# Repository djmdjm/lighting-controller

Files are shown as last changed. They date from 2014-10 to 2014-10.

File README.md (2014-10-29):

Photographic Lighting Timer
===========================

This is a small lighting controller circuit based around an AVR
microcontroller. It supports two inputs and two outputs and
configurable timing delays. The outputs use MOSFETs that should
be good for up to 50VDC and 20A.

The `board/` directory contains the Eagle files for the board and
`firmware/` contains the source for the firmware. You'll need
avr-gcc et al. to build it. `make load` will attempt to program
the firmware using my setup (avrdude w/ buspirate on
`/dev/cuaU1`).

NB. the current version of the board has not been built and the
old version that I did build had some problems that required a
bit of rework. I beat the old version into working shape and that
was good enough for my immediate needs.

Not included in the schematics are the front-panel controls: a
power toggle, momentary switch, generic rotary encoder (w/ press
switch) and 4x20 HD44870-style LCD. The switches and encoder need
pull-ups and debouncing caps.

The firmware allows triggering from logical combinations of the
inputs (e.g. "input 1 high and input 2 low"). Upon triggering it
waits a configurable delay (from 1us to ~1ksec) and enables one
or both outputs for a configurable duration. It also supports a
strobe mode that goes from milli-hertz to close to 1MHz frequency
and has adjustable duration and duty cycle.

The outputs are not isolated from each other, but they are
isolated from the inputs and the main board. Likewise the inputs
are isolated from the main board and the output but not from each
other.

This was only my 2nd attempt at cutting a board, so it's probably
terrible. You have been warned :)

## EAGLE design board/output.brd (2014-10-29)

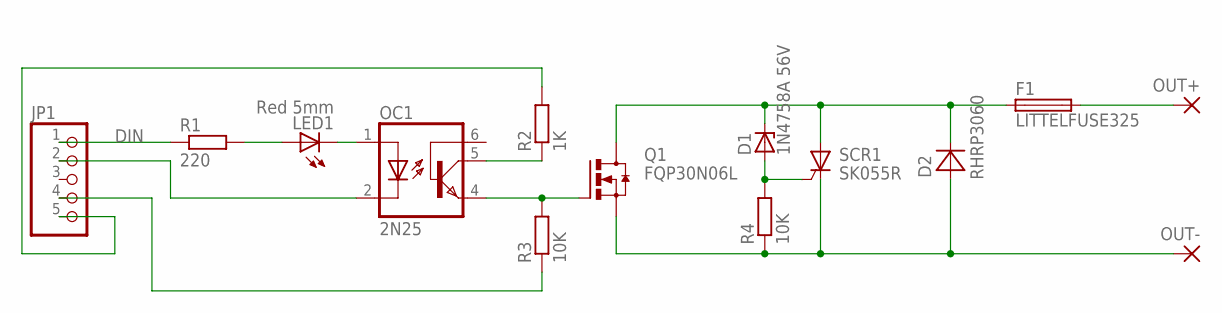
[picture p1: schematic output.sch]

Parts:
D1: 1N4758A 56V; DO41Z10
D2: RHRP3060; TO-220CAS-HS
F1: LITTELFUSE325; LITTELFUSE-325
JP1: PINHD-1X5; 1X05
LED1: Red 5mm; LED5MM
OC1: 2N25; DIL-06
OUT+: 2,54/1,1
OUT-: 2,54/1,1
Q1: FQP30N06L; TO-220BV-HS
R1: 220; 0207/10
R2: 1K; 0207/10
R3, R4: 10K; 0207/10
SCR1: SK055R; TO-220V-HS

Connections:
DGND: JP1.2, OC1.2 (C)
DIN: JP1.1, R1.1
ISOL_GND: JP1.4, R3.1
ISOL_OUT+: D1.C, D2.C, F1.P$1 (1), Q1.D, SCR1.2 (A)
ISOL_OUT-: D2.A, OUT-.1, Q1.S, R4.1, SCR1.1 (C)
ISOL_VDD: JP1.5, R2.2
unnamed: D1.A, R4.2, SCR1.3 (G)
unnamed: OC1.5 (COL), R2.1
unnamed: OC1.4 (EMI), Q1.G, R3.2
unnamed: LED1.K (C), OC1.1 (A)
unnamed: LED1.A, R1.2
unnamed: F1.P$2 (2), OUT+.1

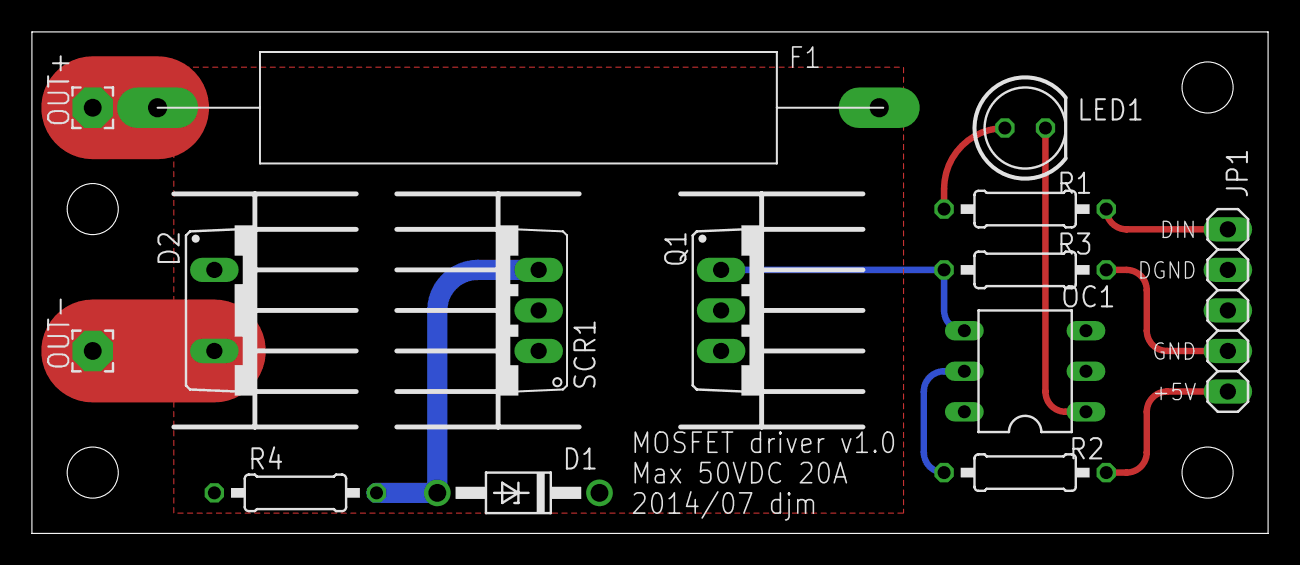
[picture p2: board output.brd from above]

Board: 2 copper layers, 77.5 x 31.4 mm, 14 parts (0 on the bottom side), 12 nets.

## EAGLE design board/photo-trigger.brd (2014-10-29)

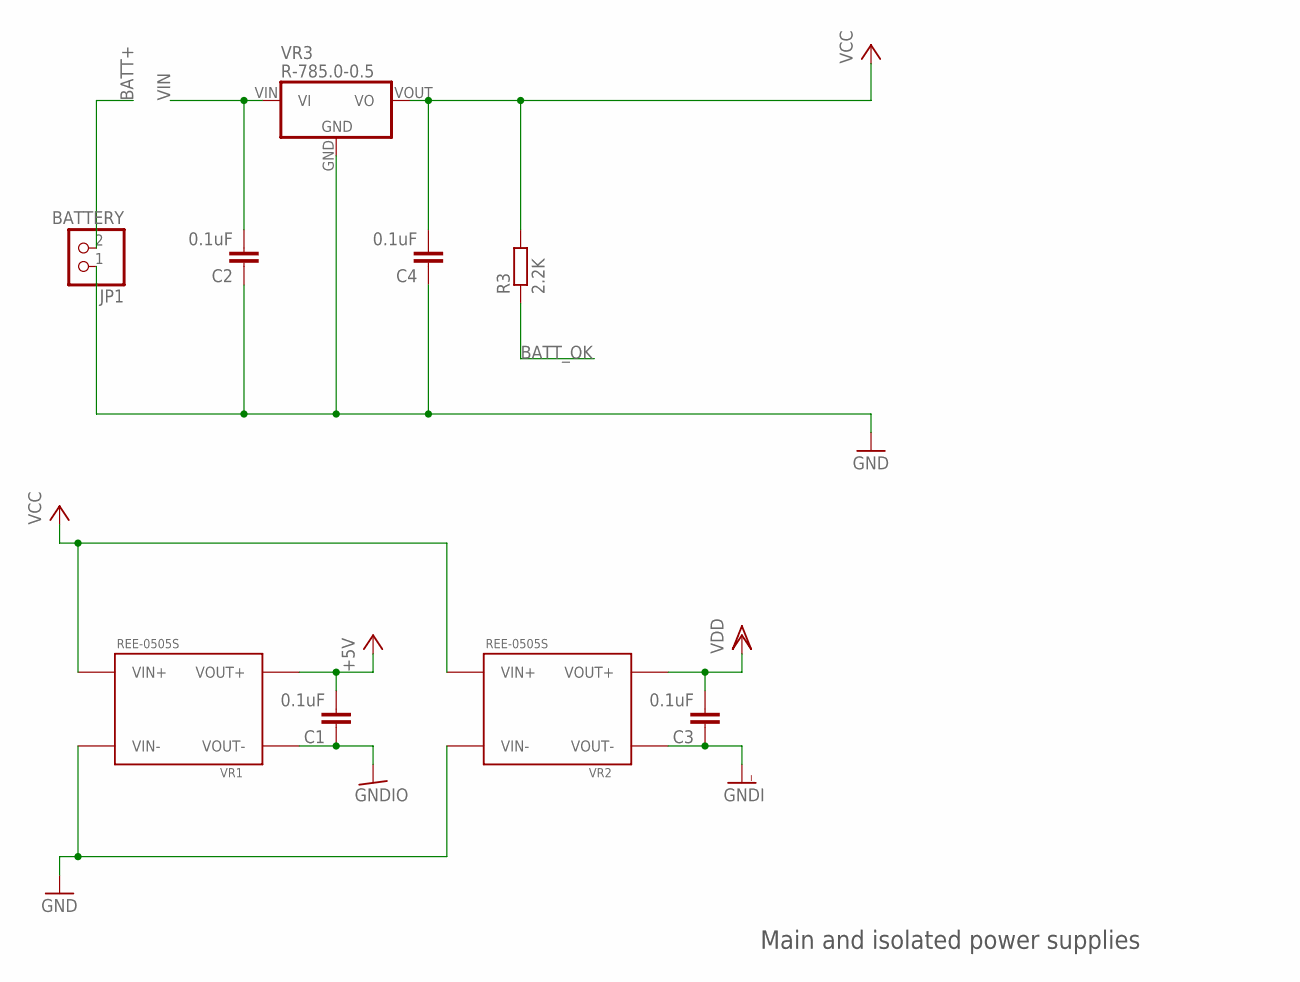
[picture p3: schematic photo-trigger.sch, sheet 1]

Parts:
C1, C2, C3, C4: 0.1uF; C050-035X075
JP1: BATTERY; 1X02
R3: 2.2K; 0207/10
VR1, VR2: REE-0505S; RECOM-REE
VR3: R-785.0-0.5; RECOM-R78

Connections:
+5V: C1.2, VR1.VOUT+; also elsewhere on the board
BATT+: JP1.2; also elsewhere on the board
BATT_OK: R3.1; also elsewhere on the board
GND: C2.1, C4.1, JP1.1, VR1.VIN-, VR2.VIN-, VR3.GND; also elsewhere on the board
GNDI: C3.1, VR2.VOUT-; also elsewhere on the board
GNDIO: C1.1, VR1.VOUT-; also elsewhere on the board
VCC: C4.2, R3.2, VR1.VIN+, VR2.VIN+, VR3.VOUT (VO); also elsewhere on the board
VDD: C3.2, VR2.VOUT+; also elsewhere on the board
VIN: C2.2, VR3.VIN (VI); also elsewhere on the board

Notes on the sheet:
Main and isolated power supplies

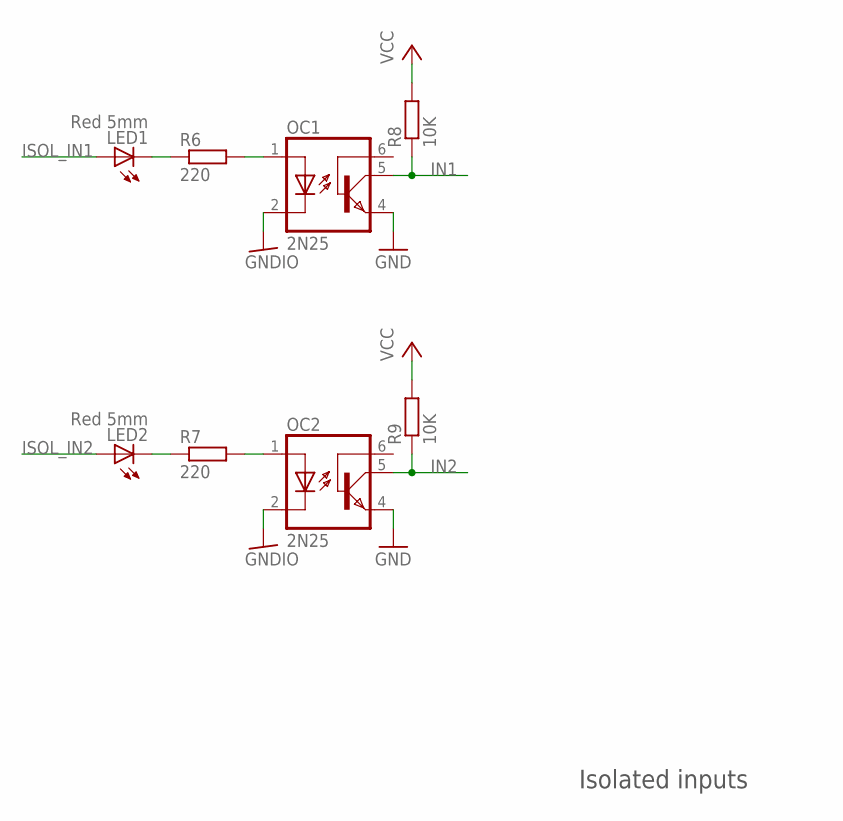
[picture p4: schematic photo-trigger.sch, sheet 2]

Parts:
LED1, LED2: Red 5mm; LED5MM
OC1, OC2: 2N25; DIL-06
R6, R7: 220; 0207/10
R8, R9: 10K; 0207/10

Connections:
GND: OC1.4 (EMI), OC2.4 (EMI); also elsewhere on the board
GNDIO: OC1.2 (C), OC2.2 (C); also elsewhere on the board
IN1: OC1.5 (COL), R8.1; also elsewhere on the board
IN2: OC2.5 (COL), R9.1; also elsewhere on the board
ISOL_IN1: LED1.A; also elsewhere on the board
ISOL_IN2: LED2.A; also elsewhere on the board
unnamed: OC1.1 (A), R6.2
unnamed: OC2.1 (A), R7.2
unnamed: LED2.K (C), R7.1
unnamed: LED1.K (C), R6.1
VCC: R8.2, R9.2; also elsewhere on the board

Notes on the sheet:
Isolated inputs

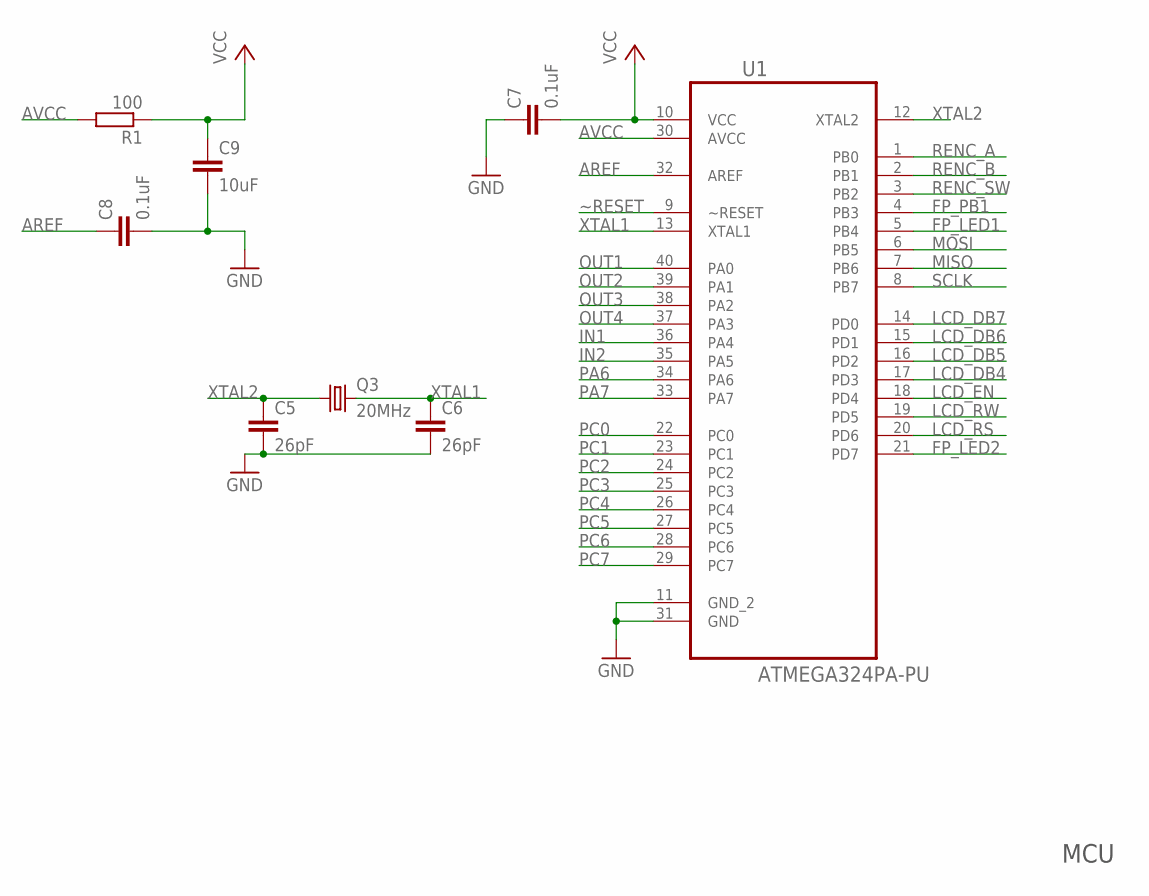
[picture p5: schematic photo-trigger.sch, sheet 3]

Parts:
C5, C6: 26pF; C025-025X050
C7, C8: 0.1uF; C050-035X075
C9: 10uF; C050-035X075
Q3: 20MHz; HC49/S
R1: 100; 0207/10
U1: ATMEGA324PA-PU; DIP254P1524X482-40

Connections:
AREF: C8.1, U1.32 (AREF)
AVCC: R1.2, U1.30 (AVCC)
FP_LED1: U1.5 (PB4); also elsewhere on the board
FP_LED2: U1.21 (PD7); also elsewhere on the board
FP_PB1: U1.4 (PB3); also elsewhere on the board
GND: C5.2, C6.2, C7.1, C8.2, C9.2, U1.11 (GND_2), U1.31 (GND); also elsewhere on the board
IN1: U1.36 (PA4); also elsewhere on the board
IN2: U1.35 (PA5); also elsewhere on the board
LCD_DB4: U1.17 (PD3); also elsewhere on the board
LCD_DB5: U1.16 (PD2); also elsewhere on the board
LCD_DB6: U1.15 (PD1); also elsewhere on the board
LCD_DB7: U1.14 (PD0); also elsewhere on the board
LCD_EN: U1.18 (PD4); also elsewhere on the board
LCD_RS: U1.20 (PD6); also elsewhere on the board
LCD_RW: U1.19 (PD5); also elsewhere on the board
MISO: U1.7 (PB6); also elsewhere on the board
MOSI: U1.6 (PB5); also elsewhere on the board
OUT1: U1.40 (PA0); also elsewhere on the board
OUT2: U1.39 (PA1); also elsewhere on the board
OUT3: U1.38 (PA2); also elsewhere on the board
OUT4: U1.37 (PA3); also elsewhere on the board
PA6: U1.34 (PA6); also elsewhere on the board
PA7: U1.33 (PA7); also elsewhere on the board
PC0: U1.22 (PC0); also elsewhere on the board
PC1: U1.23 (PC1); also elsewhere on the board
PC2: U1.24 (PC2); also elsewhere on the board
PC3: U1.25 (PC3); also elsewhere on the board
PC4: U1.26 (PC4); also elsewhere on the board
PC5: U1.27 (PC5); also elsewhere on the board
PC6: U1.28 (PC6); also elsewhere on the board
PC7: U1.29 (PC7); also elsewhere on the board
RENC_A: U1.1 (PB0); also elsewhere on the board
RENC_B: U1.2 (PB1); also elsewhere on the board
RENC_SW: U1.3 (PB2); also elsewhere on the board
SCLK: U1.8 (PB7); also elsewhere on the board
VCC: C7.2, C9.1, R1.1, U1.10 (VCC); also elsewhere on the board
XTAL1: C6.1, Q3.2, U1.13 (XTAL1)
XTAL2: C5.1, Q3.1, U1.12 (XTAL2)
~RESET: U1.9 (~RESET); also elsewhere on the board

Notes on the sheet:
MCU

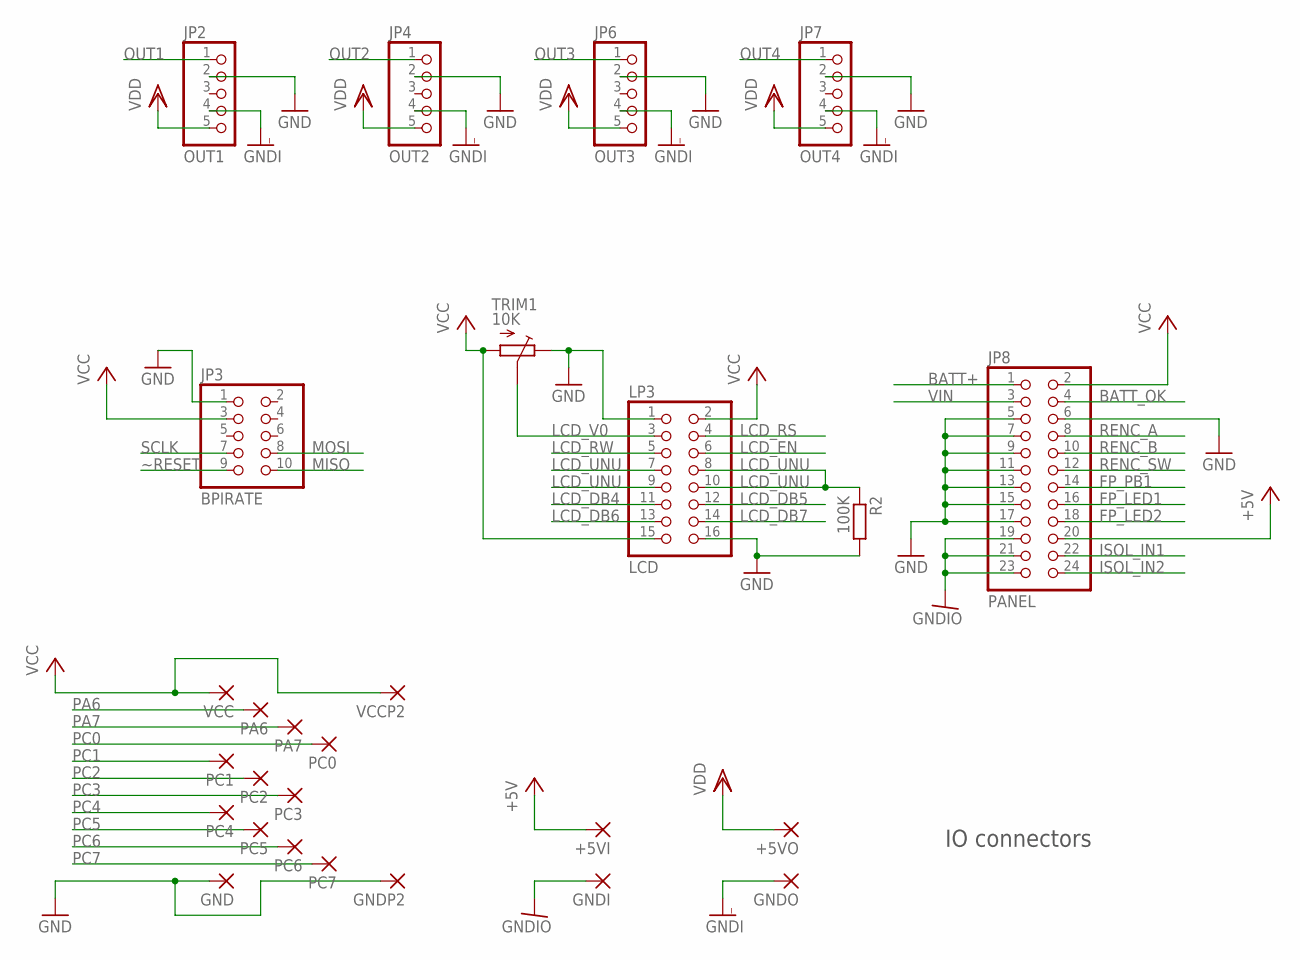
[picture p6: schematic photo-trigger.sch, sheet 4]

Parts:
+5VI: +5VI; PAD1.9/0.9
+5VO: +5VO; PAD1.9/0.9
GND: GND; PAD1.9/0.9
GNDI: GNDI; PAD1.9/0.9
GNDO: GNDO; PAD1.9/0.9
GNDP2: GND; PAD1.9/0.9
JP2: OUT1; 1X05
JP3: BPIRATE; 2X05
JP4: OUT2; 1X05
JP6: OUT3; 1X05
JP7: OUT4; 1X05
JP8: PANEL; 2X12
LP3: LCD; 2X08
PA6: PA2; PAD1.9/0.9
PA7: PA3; PAD1.9/0.9
PC0: PC0; PAD1.9/0.9
PC1: PC1; PAD1.9/0.9
PC2: PC2; PAD1.9/0.9
PC3: PC3; PAD1.9/0.9
PC4: PC4; PAD1.9/0.9
PC5: PC5; PAD1.9/0.9
PC6: PC6; PAD1.9/0.9
PC7: PC7; PAD1.9/0.9
R2: 100K; 0207/10
TRIM1: 10K; VISHAY-TRIM-63M-T607
VCC: VCC; PAD1.9/0.9
VCCP2: VCC; PAD1.9/0.9

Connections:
+5V: +5VI.P$1, JP8.20; also elsewhere on the board
BATT+: JP8.1; also elsewhere on the board
BATT_OK: JP8.4; also elsewhere on the board
FP_LED1: JP8.16; also elsewhere on the board
FP_LED2: JP8.18; also elsewhere on the board
FP_PB1: JP8.14; also elsewhere on the board
GND: GND.P$1, GNDP2.P$1, JP2.2, JP3.1, JP4.2, JP6.2, JP7.2, JP8.5, JP8.6, JP8.7, JP8.9, JP8.11, JP8.13, JP8.15, JP8.17, LP3.1, LP3.16, R2.2, TRIM1.P$3 (E); also elsewhere on the board
GNDI: GNDO.P$1, JP2.4, JP4.4, JP6.4, JP7.4; also elsewhere on the board
GNDIO: GNDI.P$1, JP8.19, JP8.21, JP8.23; also elsewhere on the board
ISOL_IN1: JP8.22; also elsewhere on the board
ISOL_IN2: JP8.24; also elsewhere on the board
LCD_DB4: LP3.11; also elsewhere on the board
LCD_DB5: LP3.12; also elsewhere on the board
LCD_DB6: LP3.13; also elsewhere on the board
LCD_DB7: LP3.14; also elsewhere on the board
LCD_EN: LP3.6; also elsewhere on the board
LCD_RS: LP3.4; also elsewhere on the board
LCD_RW: LP3.5; also elsewhere on the board
LCD_UNU: LP3.7, LP3.8, LP3.9, LP3.10, R2.1
LCD_V0: LP3.3, TRIM1.P$2 (S)
MISO: JP3.10; also elsewhere on the board
MOSI: JP3.8; also elsewhere on the board
OUT1: JP2.1; also elsewhere on the board
OUT2: JP4.1; also elsewhere on the board
OUT3: JP6.1; also elsewhere on the board
OUT4: JP7.1; also elsewhere on the board
PA6: PA6.P$1; also elsewhere on the board
PA7: PA7.P$1; also elsewhere on the board
PC0: PC0.P$1; also elsewhere on the board
PC1: PC1.P$1; also elsewhere on the board
PC2: PC2.P$1; also elsewhere on the board
PC3: PC3.P$1; also elsewhere on the board
PC4: PC4.P$1; also elsewhere on the board
PC5: PC5.P$1; also elsewhere on the board
PC6: PC6.P$1; also elsewhere on the board
PC7: PC7.P$1; also elsewhere on the board
RENC_A: JP8.8; also elsewhere on the board
RENC_B: JP8.10; also elsewhere on the board
RENC_SW: JP8.12; also elsewhere on the board
SCLK: JP3.7; also elsewhere on the board
VCC: JP3.3, JP8.2, LP3.2, LP3.15, TRIM1.P$1 (A), VCC.P$1, VCCP2.P$1; also elsewhere on the board
VDD: +5VO.P$1, JP2.5, JP4.5, JP6.5, JP7.5; also elsewhere on the board
VIN: JP8.3; also elsewhere on the board
~RESET: JP3.9; also elsewhere on the board

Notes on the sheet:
IO connectors

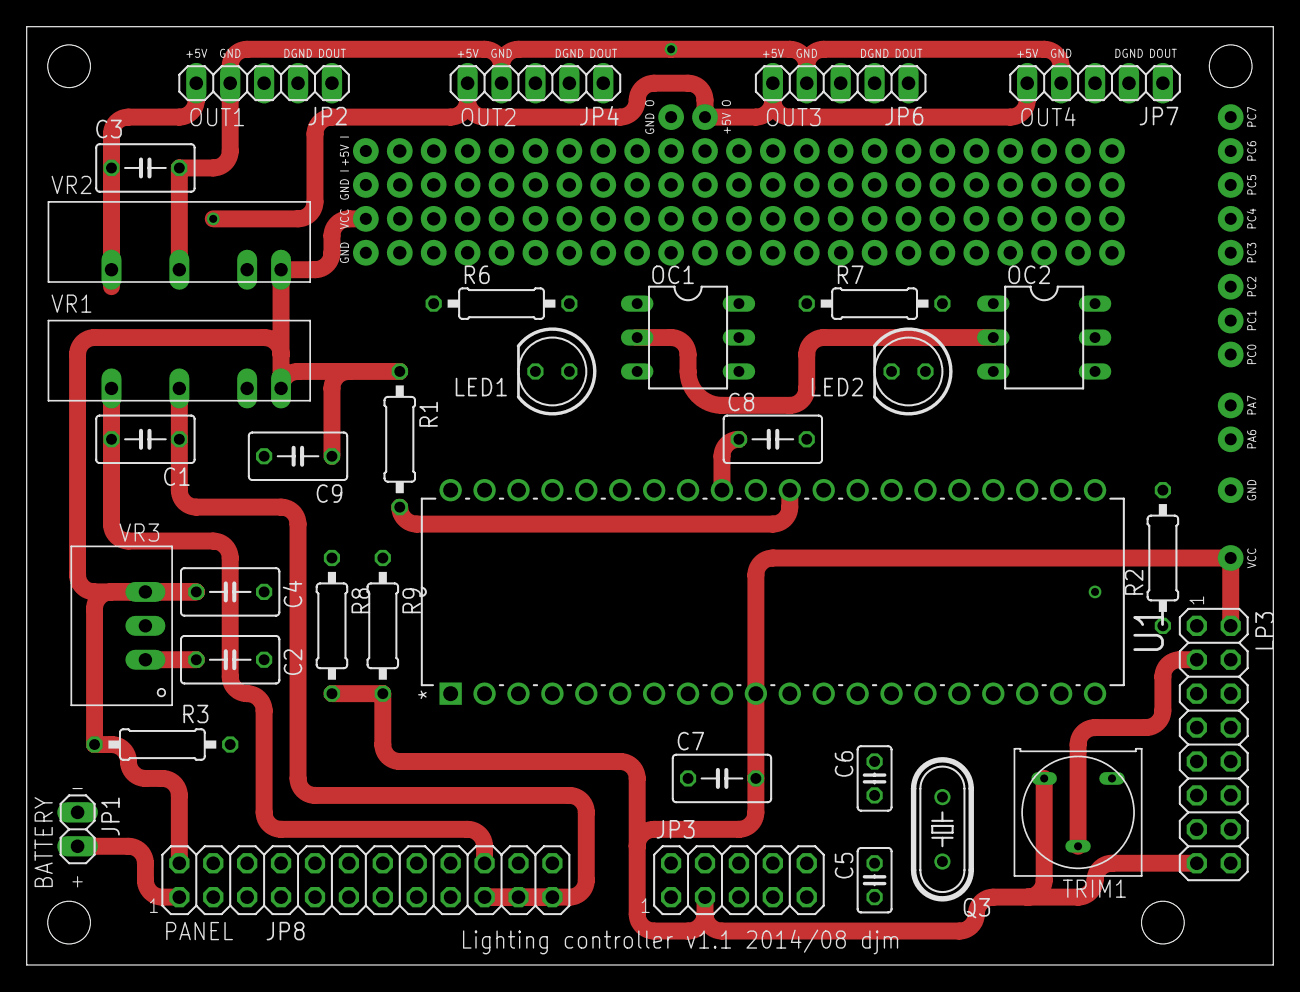
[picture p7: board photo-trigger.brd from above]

Board: 4 copper layers, 93.4 x 70.3 mm, 52 parts (0 on the bottom side), 54 nets.

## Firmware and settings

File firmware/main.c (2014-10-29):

/*
 * Copyright (c) 2013 Damien Miller <djm@mindrot.org>
 *
 * Permission to use, copy, modify, and distribute this software for any
 * purpose with or without fee is hereby granted, provided that the above
 * copyright notice and this permission notice appear in all copies.
 *
 * THE SOFTWARE IS PROVIDED "AS IS" AND THE AUTHOR DISCLAIMS ALL WARRANTIES
 * WITH REGARD TO THIS SOFTWARE INCLUDING ALL IMPLIED WARRANTIES OF
 * MERCHANTABILITY AND FITNESS. IN NO EVENT SHALL THE AUTHOR BE LIABLE FOR
 * ANY SPECIAL, DIRECT, INDIRECT, OR CONSEQUENTIAL DAMAGES OR ANY DAMAGES
 * WHATSOEVER RESULTING FROM LOSS OF USE, DATA OR PROFITS, WHETHER IN AN
 * ACTION OF CONTRACT, NEGLIGENCE OR OTHER TORTIOUS ACTION, ARISING OUT OF
 * OR IN CONNECTION WITH THE USE OR PERFORMANCE OF THIS SOFTWARE.
 */

#include <avr/io.h>
#include <avr/interrupt.h>
#include <avr/sleep.h>
#include <util/delay.h>
#include <stddef.h>
#include <stdint.h>
#include <string.h>

#include "lcd.h"
#include "num_format.h"
#include "encoder.h"
#include "event.h"
#include "event-types.h"
#include "ui.h"

static int pb_encoder = 1;
static int pb_button = 0;
static int running = 0;

/* Interrupt for the digitial inputs */
ISR(PCINT0_vect)
{
	/* Nothing here - we just need an interrupt to leave sleep. */
}

/* Interrupt for pushbuttons and the rotaty encoder */
ISR(PCINT1_vect)
{
	int pb;

	if (running)
		return; /* no events */

	encoder_interrupt();
	pb = (PINB >> 2) & 1;
	if (pb != pb_encoder) {
		/* NB. encoder button is active-low */
		event_enqueue(EV_BUTTON, 0, !pb, 0, 0);
		pb_encoder = pb;
	}
	pb = (PINB >> 3) & 1;
	if (pb != pb_button) {
		event_enqueue(EV_BUTTON, 1, pb, 0, 0);
		pb_button = pb;
	}
}

static void
sleep_for_interrupt(void)
{
	set_sleep_mode(SLEEP_MODE_IDLE);
	cli();
	sleep_enable();
	sei();
	sleep_cpu();
	sleep_disable();
}

static int
evaluate_input(int channel_mode)
{
	/* Digital inputs and encoder are active-high */
	switch (channel_mode) {
	case TRIG_CHAN_1:
		return (PINA & (1<<4)) == 0;
	case TRIG_CHAN_1_NOT:
		return (PINA & (1<<4)) != 0;
	case TRIG_CHAN_2:
		return (PINA & (1<<5)) == 0;
	case TRIG_CHAN_2_NOT:
		return (PINA & (1<<5)) != 0;
	case TRIG_MANUAL:
		return (PINB & (1<<3)) == 0;
	case TRIG_NONE:
	default:
		return 0;
	}
}

static uint32_t
duration_to_cycles(int n, int unit)
{
	switch (unit) {
	case DUR_MICROSEC:
		return n * (F_CPU / 1000000);
	case DUR_MILLISEC:
		return n * (F_CPU / 1000);
	case DUR_SEC:
		return n * F_CPU;
	}
	return 0;
}

static uint32_t
freq_to_cycles(int f, int unit)
{
	switch (unit) {
	case RATE_MHZ:
		return (F_CPU / 1000000) / f;
	case RATE_KHZ:
		return (F_CPU / 1000) / f;
	case RATE_HZ:
		return F_CPU / f;
	case RATE_MILLI_HZ:
		return (F_CPU * 1000) / f;
	}
	return 0;
}

/*
 * prepare_wait() / LONG_WAIT() implement delays accurate to 6 cycles
 * over ranges up to ~1k sec.
 */

struct longwait {
	uint32_t t50m;
	uint16_t t768;
	uint8_t t3;
	uint8_t tiny;
};

static void
dump_longwait(struct longwait *lw) {
	lcd_string(ntod(lw->t50m));
	lcd_char(' ');
	lcd_string(ntod(lw->t768));
	lcd_char(' ');
	lcd_string(ntod(lw->t3));
	lcd_char(' ');
	lcd_string(ntod(lw->tiny));
	lcd_clear_eol();
}

static void
prepare_wait(uint32_t t, struct longwait *lw)
{
	memset(lw, 0, sizeof(*lw));
	/* Tiny delays use nop sled */
	if (t < 40) {
		lw->tiny = 40 - (t < 14 ? 0 : t - 14);
		return;
	}
	/* Take off some cycles for comparisons (determined empirically) */
	t -= 36;
	lw->t50m = t / 50000000; /* ~max 256*3 cycles that fit a u16 */
	t %= 50000000;
	lw->t768 = t / 768; /* Max _delay_loop_1() length = 236*3 cycles */
	t %= 768;
	lw->t3 = t / 3; /* _delay_loop_1() takes 3 cycles per loop */
}

#define LONG_WAIT(lw) do { \
	uint32_t __i; \
	uint16_t __j; \
	\
	if (lw.tiny != 0) { \
		/* Really short delays jump into a nop sled */ \
		__asm__ volatile ( \
			"ldi r31, pm_hi8(1f)" "\n\t" \
			"ldi r30, pm_lo8(1f)" "\n\t" \
			"add r30, %0" "\n\t" \
			"adc r31, __zero_reg__" "\n\t" \
			"ijmp" "\n\t" \
			"1:" "\n\t" \
			"nop" "\n\t" \
			"nop" "\n\t" \
			"nop" "\n\t" \
			"nop" "\n\t" \
			"nop" "\n\t" \
			"nop" "\n\t" \
			"nop" "\n\t" \
			"nop" "\n\t" \
			"nop" "\n\t" \
			"nop" "\n\t" \
			"nop" "\n\t" \
			"nop" "\n\t" \
			"nop" "\n\t" \
			"nop" "\n\t" \
			"nop" "\n\t" \
			"nop" "\n\t" \
			"nop" "\n\t" \
			"nop" "\n\t" \
			"nop" "\n\t" \
			"nop" "\n\t" \
			"nop" "\n\t" \
			"nop" "\n\t" \
			"nop" "\n\t" \
			"nop" "\n\t" \
			"nop" "\n\t" \
			"nop" "\n\t" \
			"nop" "\n\t" \
			"nop" "\n\t" \
			"nop" "\n\t" \
			"nop" "\n\t" \
			"nop" "\n\t" \
			"nop" "\n\t" \
			"nop" "\n\t" \
			"nop" "\n\t" \
			"nop" "\n\t" \
			"nop" "\n\t" \
			"nop" "\n\t" \
			"nop" "\n\t" \
			"nop" "\n\t" \
			"nop" "\n\t" \
			: /* no output */ \
			: "l" (lw.tiny) \
			: "r30", "r31" \
		); \
	} else { \
		/* Longer delays use the smallest possible counter */ \
		for (__i = lw.t50m; __i != 0; __i--) \
			__builtin_avr_delay_cycles(50000000); \
		for (__j = lw.t768; __j != 0; __j--) \
			__builtin_avr_delay_cycles(762); /* empirical */ \
		if (lw.t3 != 0) /* time == 0 means sleep for 256*3 cycles! */ \
			_delay_loop_1(lw.t3); \
	} \
} while (0)

static void
timing_test(void)
{
	struct longwait on, off;

	lcd_setup();
	lcd_display(1, 0, 1);

	DDRA = 0x0f;
	memset(&on, 0, sizeof(on));
	memset(&off, 0, sizeof(on));
	prepare_wait(1, &on);
	prepare_wait(804, &off);

	lcd_moveto(0, 0);
	dump_longwait(&on);
	lcd_moveto(0, 1);
	dump_longwait(&off);

	for (;;) {
		PORTA = 0x0f;
		LONG_WAIT(on);
		PORTA = 0;
		LONG_WAIT(off);
	}
}

int
main(void)
{
	int i, ready1, ready2, done;
	uint32_t j, wait1, wait2, on, off, holdoff, cycle_len, duration, ncyc;
	struct longwait wait1_l, wait2_l, on_l, off_l, holdoff_l, cycle_len_l;
	uint8_t off_before_ch2, strobe_out;

	/*
	 * NB. external xtal. To select "write lfuse 0 0x6f"
	 */
	CLKPR = 0x80;
	CLKPR = 0x00; /* 20 MHz */

	if (0)
		timing_test();

	/* Turn all pin change interrupts off by default */
	PCICR = 0x00;
	PCMSK0 = 0x00;
	PCMSK1 = 0x00;
	PCMSK2 = 0x00;
	PCMSK3 = 0x00;

	/* I/O port direction */
	DDRA = 0x0f; /* 0-1: digital out 4-5: digital in */
	DDRB = (1 << 4); /* 0-2: encoder 3: button 4: LED1 */
	DDRD = (1 << 7); /* 7: LED2 */
	PORTB = 0x00;
	PORTD = 0x00;
	PORTA = 0x00;

	lcd_setup();
	lcd_display(1, 0, 1);
	lcd_string("OK ");
	lcd_moveto(0, 0);

	reset_config();
	event_setup();
	encoder_setup();

	/* Enable interrupts for buttons */
	PCMSK1 |= (1 << 2)|(1 << 3);
	PCICR |= (1 << PCIE1);

	sei();

	for (;;) {
		/* Disable interrupts for inputs */
		PCMSK0 &= ~((1 << 4) | (1 << 5));
		PCICR &= ~(1 << PCIE0);

		/* Drain any queued events */
		event_drain();
		running = 0;

		/* Input lights off */
		PORTB &= ~(1 << 4);
		PORTD &= ~(1 << 7);

		/*
		 * Let the user edit the configuration. This ends when they
		 * select "ready".
		 */
		config_edit();

		/* In running mode now */
		cli();
		running = 1; /* Accessed in interrupt handler */
		sei();
		lcd_display(1, 0, 0);

		/* Calculate delays. */
		wait1 = duration_to_cycles(cfg.wait, cfg.wait_unit);
		wait2 = duration_to_cycles(cfg.wait2, cfg.wait_unit);
		on = duration_to_cycles(cfg.on, cfg.on_unit);
		holdoff = duration_to_cycles(cfg.holdoff, cfg.holdoff_unit);
		duration = duration_to_cycles(cfg.len, cfg.len_unit);
		cycle_len = freq_to_cycles(cfg.freq, cfg.freq_unit);
		ncyc = (duration + cycle_len - 1) / cycle_len;

		if (on > cycle_len)
			on = cycle_len - 1;
		if (on == 0 || (cfg.mode == MODE_STROBE &&
		    (on >= cycle_len || ncyc < 1))) {
			lcd_clear();
			lcd_string("INVALID PARAMETERS");
			_delay_ms(5 * 1000);
			cfg.ready = READY_NO;
			continue;
		}
		off = cycle_len - on;

		off_before_ch2 = 0;
		if (cfg.mode == MODE_ONESHOT) {
			if (on < wait2) {
				off_before_ch2 = 1;
				wait2 -= on;
			} else {
				off_before_ch2 = 0;
				on -= wait2;
			}
		}

		/* Turn the input lights on */
		if (cfg.trigger[0] == TRIG_CHAN_1 ||
		    cfg.trigger[0] == TRIG_CHAN_1_NOT ||
		    cfg.trigger[1] == TRIG_CHAN_1 ||
		    cfg.trigger[1] == TRIG_CHAN_1_NOT)
			PORTB |= (1 << 4);
		if (cfg.trigger[0] == TRIG_CHAN_2 ||
		    cfg.trigger[0] == TRIG_CHAN_2_NOT ||
		    cfg.trigger[1] == TRIG_CHAN_2 ||
		    cfg.trigger[1] == TRIG_CHAN_2_NOT)
			PORTD |= (1 << 7);

		/* Enable interrupt for inputs. */
		PCMSK0 |= (1 << 4) | (1 << 5);
		PCICR |= (1 << PCIE0);

		for (done = 0; !done;) {
			lcd_moveto(0, 0);
			lcd_string("** RUNNING: ");
			lcd_string(cfg.mode == MODE_ONESHOT ?
			    "ONESHOT" : "STROBE");
			lcd_clear_eol();

			/* Prepare output value for strobe */
			switch (cfg.output) {
			case OUT_CH1:
				strobe_out = (1 << 1);
				break;
			case OUT_CH2:
				strobe_out = (1 << 0);
				break;
			case OUT_BOTH:
				strobe_out = (1 << 0) | (1 << 1);
				break;
			default:
				strobe_out = 0;
			}

			/* Prepare timer values */
			prepare_wait(wait1, &wait1_l);
			prepare_wait(wait2, &wait2_l);
			prepare_wait(on, &on_l);
			prepare_wait(holdoff, &holdoff_l);
			prepare_wait(off, &off_l);

#ifdef DEBUG_RUN
			lcd_moveto(0, 0);
			dump_longwait(&holdoff_l);
#endif

			/* XXX fudge these times for comparison, etc. costs */
			/* XXX vary sleep mode for delay? */

			/* Wait for input. */
			event_drain();
			sleep_for_interrupt();

			/* Terminate running state on encoder press */
			if ((PINB & (1 << 2)) == 0)
				break;

#ifdef DEBUG_RUN
			lcd_moveto(0, 0);
			lcd_string("** WAKEUP");
			lcd_clear_eol();
#endif

			/* Evaluate trigger inputs */
			ready1 = evaluate_input(cfg.trigger[0]);
			ready2 = evaluate_input(cfg.trigger[1]);
			switch (cfg.combine) {
			case COMBINE_OR:
				if (!(ready1 || ready2))
					continue;
				break;
			case COMBINE_AND:
				if (!(ready1 && ready2))
					continue;
				break;
			case COMBINE_XOR:
				if (!(ready1 ^ ready2))
					continue;
				break;
			case COMBINE_NONE:
			default:
				if (!ready1)
					continue;
				break;
			}

#ifdef DEBUG_RUN
			lcd_moveto(0, 0);
			lcd_string("** TRIGGERED");
			lcd_clear_eol();
#endif

			/* Wait initial delay. */
			LONG_WAIT(wait1_l);

#ifdef DEBUG_RUN
			lcd_moveto(0, 0);
			lcd_string("** GO");
			lcd_clear_eol();
#endif

			if (cfg.mode == MODE_ONESHOT) {
				/* Output on */
				switch (cfg.output) {
				case OUT_CH1:
					PORTA = (1 << 1);
					LONG_WAIT(on_l);
					PORTA = 0;
					break;
				case OUT_CH2:
					PORTA = (1 << 0);
					LONG_WAIT(on_l);
					PORTA = 0;
					break;
				case OUT_BOTH:
					PORTA = (1 << 1);
					if (off_before_ch2) {
						LONG_WAIT(on_l);
						PORTA = 0;
						LONG_WAIT(wait2_l);
						PORTA = (1 << 0);
						LONG_WAIT(on_l);
						PORTA = 0;
					} else {
						LONG_WAIT(wait2_l);
						PORTA = (1 << 0) | (1 << 1);
						LONG_WAIT(on_l);
						PORTA = (1 << 0);
						LONG_WAIT(wait2_l);
						PORTA = 0;
					}
					break;
				}
				if (cfg.holdoff == -1) {
					done = 1;
					break;
				}
				lcd_moveto(0, 0);
				lcd_string("** HOLDOFF");
				lcd_clear_eol();
				LONG_WAIT(holdoff_l);
			} else {
				for (j = 0; j < ncyc; j++) {
					PORTA = strobe_out;
					LONG_WAIT(on_l);
					PORTA = 0;
					LONG_WAIT(off_l);
				}
				/*
				 * If we are not in manual trigger, then
				 * drop back to editor for explicit re-arming.
				 */
				if (cfg.trigger[0] != TRIG_MANUAL &&
				    cfg.trigger[1] != TRIG_MANUAL) {
					done = 1;
					break;
				}
			}
		}
		/* Run completed - back to edit mode */
		cfg.ready = READY_NO;
	}
	/* NOTREACHED */
}

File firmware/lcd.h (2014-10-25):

#ifndef LCD_H
#define LCD_H

/*
 * Copyright (c) 2013 Damien Miller <djm@mindrot.org>
 *
 * Permission to use, copy, modify, and distribute this software for any
 * purpose with or without fee is hereby granted, provided that the above
 * copyright notice and this permission notice appear in all copies.
 *
 * THE SOFTWARE IS PROVIDED "AS IS" AND THE AUTHOR DISCLAIMS ALL WARRANTIES
 * WITH REGARD TO THIS SOFTWARE INCLUDING ALL IMPLIED WARRANTIES OF
 * MERCHANTABILITY AND FITNESS. IN NO EVENT SHALL THE AUTHOR BE LIABLE FOR
 * ANY SPECIAL, DIRECT, INDIRECT, OR CONSEQUENTIAL DAMAGES OR ANY DAMAGES
 * WHATSOEVER RESULTING FROM LOSS OF USE, DATA OR PROFITS, WHETHER IN AN
 * ACTION OF CONTRACT, NEGLIGENCE OR OTHER TORTIOUS ACTION, ARISING OUT OF
 * OR IN CONNECTION WITH THE USE OR PERFORMANCE OF THIS SOFTWARE.
 */

/* Driver for a HD44870-style 20x2 LCD */

#define LCD_ROWS	4
#define LCD_COLS	20

/*
 * Pin/port configuration. It's possible to have the control and data signals
 * on different ports.
 */
#define LCD_CTL_DDR	DDRD
#define LCD_CTL_PORT	PORTD
#define LCD_CTL_RS	6
#define LCD_CTL_RW	5

#define LCD_EN_DDR	DDRD
#define LCD_EN_PORT	PORTD
#define LCD_EN		4

#define LCD_DB_DDR	DDRD
#define LCD_DB_PORT	PORTD
#define LCD_DB_PIN	PIND
#define LCD_DB_4	3
#define LCD_DB_5	2
#define LCD_DB_6	1
#define LCD_DB_7	0

/* LCD special characters */
#define LCD_CHAR_ARROW_R	0x7e
#define LCD_CHAR_ARROW_L	0x7f
/* XXX TODO: Japanese characters if I ever need them; 0xa1-0xdf */
#define LCD_CHAR_DEGREES	0xdf	/* Actually a maru diacritic */
#define LCD_CHAR_ALPHA		0xe0
#define LCD_CHAR_A_UMLAUT	0xe1
#define LCD_CHAR_BETA		0xe2
#define LCD_CHAR_EPSILON	0xe3
#define LCD_CHAR_MU		0xe4
#define LCD_CHAR_SIGMA		0xe5
#define LCD_CHAR_RHO		0xe6
/* 0xe7 is a stylised 'g'; doesn't look like gamma */
#define LCD_CHAR_SQRT		0xe8
#define LCD_CHAR_INV		0xe9 /* ^{-1} */
#define LCD_CHAR_U_ASTERISK	0xea /* ^{*} */
/* 0xeb is a stylised 'j'; no idea... */
#define LCD_CHAR_CENT		0xec
/* 0xed looks like a superscripted Hiragana 'mo' */
#define LCD_CHAR_N_MACRON	0xee
#define LCD_CHAR_O_UMLAUT	0xef
/* 0xf0 is a stylised 'p'; no idea... */
/* 0xf1 is a stylised 'q'; maybe a vertically-mirrored 'p'; cyrillic? */
#define LCD_CHAR_THETA		0xf2
#define LCD_CHAR_INFINITY	0xf3 /* At least I guess so... */
#define LCD_CHAR_OMEGA		0xf4
#define LCD_CHAR_U_UMLAUT	0xf5
#define LCD_CHAR_U_SIGMA	0xf6
#define LCD_CHAR_PI		0xf7
#define LCD_CHAR_X_BAR		0xf8 /* no idea... maybe multiplication? */
/* 0xf9 is a stylised 'y'; no idea... */
#define LCD_CHAR_SEN		0xfa /* Kanji for thousand */
#define LCD_CHAR_MAN		0xfb /* Kanji for ten thousand */
#define LCD_CHAR_YEN		0xfc
#define LCD_CHAR_DIVIDE		0xfd
/* 0xfe is blank */
#define LCD_CHAR_BLOCK		0xff


/*
 * Prepare the display.
 * After this the LCD will be blank with cursor visible.
 */
void lcd_setup(void);

/* Turn the display, cursor and cursor blinking off or on */
void lcd_display(int display_on, int cursor_on, int blink_on);

/*
 * Control the entry mode, whether text flow is left-to-right (rtl = 0) or
 0 right-to-left (rtl = 1) and whether the cursor shifts after text entry
 * (shift = 0) or the text * shifts and the cursor remains stationary
 * (shift = 1).
 */
void lcd_entry_mode(int rtl, int shift);

/* Clear the screen */
void lcd_clear(void);

/* Clear to the end of line only */
void lcd_clear_eol(void);

/* Return the cursor to (0, 0) */
void lcd_home(void);

/*
 * Move the cursor to a particular location. Out-of-bounds locations will
 * cause an error to be displayed.
 */
void lcd_moveto(int x, int y);

/* Return the current cursor position */
void lcd_getpos(int *x, int *y);

/*
 * Write a string at the current cursor position. Strings that won't fit
 * the display will be truncated.
 */
void lcd_string(const char *s);

/*
 * Write an array of characters to the screen. Useful for writing the
 * \0 custom character.
 */
void lcd_chars(const char *s, size_t len);

/* Write a single character to the screen. */
void lcd_char(char c);

/* Write 'n' characters of 'c' to the screen. */
void lcd_fill(char c, size_t n);

/*
 * Program one of the user-defined characters.
 * data must be an 8 byte array containing the row bitmaps of the character.
 */
void lcd_program_char(int c, uint8_t *data, size_t len);

#endif /* LCD_H */

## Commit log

2013-10-27 add basic SPI convenience routines and a tiny AD56x8 driver; just enough to setup the chip and get it to do conversions.
2013-10-30 move the SS of my AD5688 to PORTE to free up an interruptable PORTB pin for some other stuff.
2013-10-30 we don't use SS in the SPI API, so nuke it entirely
2013-10-30 driver for common two-wire quadrature rotary encoders, using interrupts.
2013-11-21 support SPI devices that sample on the leading edge of SCLK
    setup SS line; apparently if it is configured as an input it will
    put the AVR into SPI slave mode automatically!
2013-11-21 move the interrupt logic into its own function and make the setup of the handler optional, for cases where we need to tie it in with other handlers
2013-11-21 WIP MCP23S1[78] 16-pin SPI I/O multiplexer driver; still with loads of debug/tryout gunk included
2013-11-21 add MCP23S1x driver
2013-11-28 working on a Teensy 2.0 now; change MCU type
2013-11-28 working MCP23S1X driver; enough to setup, control I/O direction and read/write pins.
2014-07-28 import my EAGLE files
    [output.brd, output.sch, photo-trigger.brd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]
2014-07-30 correct device name to match library
    [photo-trigger.brd, photo-trigger.sch]
2014-07-30 correct diode lead order in part/package name
    MUR860 and RHRP3060 have pin 1 as cathode and pin 2 as anode,
    so s/TO-220AC/TO-220CA/ to avoid confusion.
    [output.brd, output.sch]
2014-08-11 fix DAC output setting
    [ad56x8.c]
2014-08-11 add support for interrupts and input bit flipping
2014-08-11 working prototype of digital side of sequencer
    runs fixed output sequence continually
    [encoder.h, main.c]
2014-08-11 rework event queue a little
    events now contain 3 x uint8 values (enough for our MIDI needs)
    [encoder.c]
2014-08-11 breadboard prototype configuration/test harness
    MIDI->CV and CV sequencer
2014-08-15 revised after building v1.0 boards; lots of fixes
    ripped out power status indicator circuit - it didn't work.
    replaced with a simple power LED.
    fixed footprint problem for Recom REE isolated VRMs
    rewired LCD socket to be easier to handle at the LCD end
    fixed MCU AREF and AGND
    expanded prototype area; embiggened pads to make them easier to
    solder
    [photo-trigger.brd, photo-trigger.sch]
2014-08-15 few more layout tweaks; embiggen more wirepads
    [photo-trigger.brd, photo-trigger.sch]
2014-08-15 v2.1 to pull in updated footprints
    embiggened drills and pads
2014-08-15 move drills to avoid heatsinks
2014-10-29 add event_drain() and event_sleep()
    event_drain() drains all events from the queue.
    event_sleep() enters one of the AVR sleep modes until
    an interrupt generates an event.
2014-10-29 interrupt control methods and a bit of debouncing
    Added encoder_interrupt_enable() and encoder_interrupt_disable()
    Added a 50us delay to the interrupt handler to allow input to
    settle.
2014-10-29 add EV_BUTTON event for button presses
2014-10-29 prune for inclusion in separate project
    [output.brd, output.sch, photo-trigger.brd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]
